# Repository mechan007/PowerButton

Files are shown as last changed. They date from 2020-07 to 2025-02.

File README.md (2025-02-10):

This is my first project on GitHub

This project was created out of the need to turn on and off a 3D printer with a button on the front panel. 
The emphasis was on powering the module directly from the mains voltage, also on the possible implementation
in existing devices, a button on the front panel and preventing shutdown by accidentally pressing the button.

The project is functional, but not finished (perhaps a prototype?),
it is intended for people who are familiar with this area.

Hopefully I will be able to continue and improve it.

I am also open to your questions, comments and suggestions,
but I warn you in advance that I am not able to respond immediately.

!!!Warning!!! This project uses high (mains) voltage! And can severely damage health, or cause death,
especially to people who do not know what they are doing! This project is not a final product,
it is not a recommendation or a guide! Everything you do with this, you do at your own risk!

Thank you for reading this far...

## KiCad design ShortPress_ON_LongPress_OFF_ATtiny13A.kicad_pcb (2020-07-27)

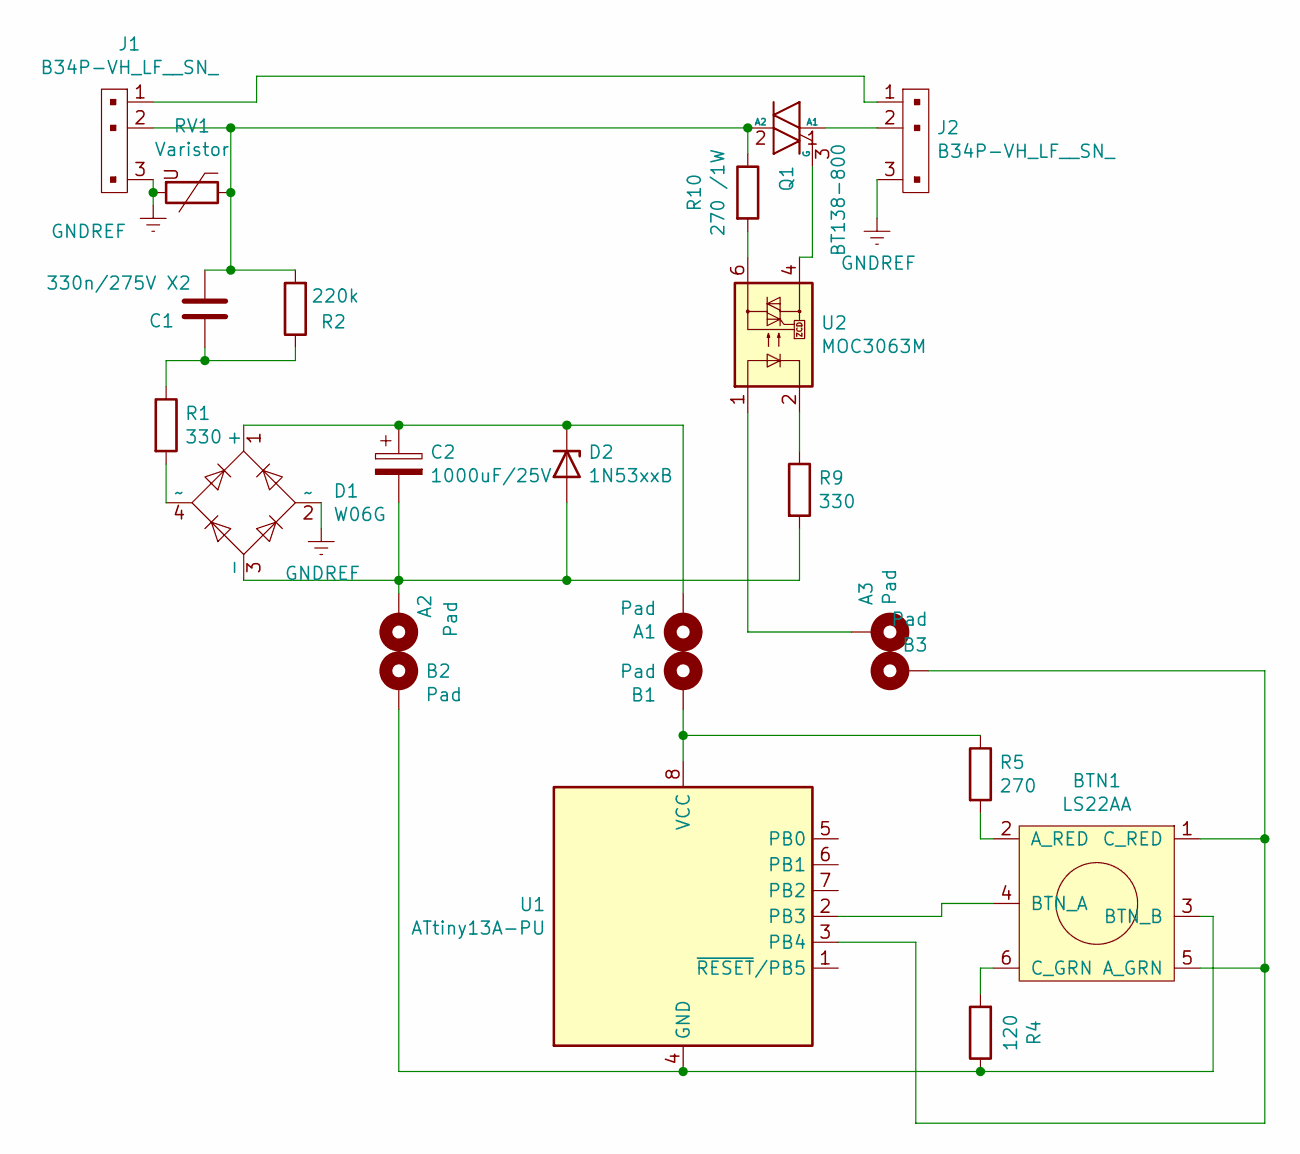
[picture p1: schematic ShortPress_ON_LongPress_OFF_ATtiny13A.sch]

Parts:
A1, A2, A3: Pad; PinHeader_1x01_P1.00mm_Vertical
B1, B2, B3: Pad; PinHeader_1x01_P1.00mm_Vertical
BTN1: LS22AA
C1: 330n/275V X2; C_Rect_L18.0mm_W8.0mm_P15.00mm_FKS3_FKP3
C2: 1000uF/25V; CP_Radial_D10.0mm_P5.00mm
D1: W06G; Diode_Bridge_Round_D9.8mm
D2: 1N53xxB; D_DO-201_P15.24mm_Horizontal
J1, J2: B34P-VH_LF__SN_; PinHeader_1x3_4_P3.96mm_Drill1.6mm
Q1: BT138-800; TO-220-3_Vertical
R1, R9: 330; R_Axial_DIN0207_L6.3mm_D2.5mm_P10.16mm_Horizontal
R2: 220k; R_Axial_DIN0207_L6.3mm_D2.5mm_P10.16mm_Horizontal
R4: 120; R_Axial_DIN0207_L6.3mm_D2.5mm_P10.16mm_Horizontal
R5: 270; R_Axial_DIN0207_L6.3mm_D2.5mm_P10.16mm_Horizontal
R10: 270 /1W; R_Axial_DIN0414_L11.9mm_D4.5mm_P15.24mm_Horizontal
RV1: Varistor; RV_Disc_D15.5mm_W4.8mm_P7.5mm
U1: ATtiny13A-PU; DIP-8_W7.62mm
U2: MOC3063M; DIP-6_W7.62mm

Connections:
GNDREF: D1.2 (~~), J1.3, J2.3, RV1.2
unnamed: A1.1, C2.1, D1.1 (+), D2.1 (K)
unnamed: A2.1, C2.2, D1.3 (-), D2.2 (A), R9.2
unnamed: A3.1, U2.1
unnamed: B1.1, R5.1, U1.8 (VCC)
unnamed: B2.1, BTN1.3 (BTN_B), R4.1, U1.4 (GND)
unnamed: B3.1, BTN1.1 (C_RED), BTN1.5 (A_GRN), U1.3 (PB4)
unnamed: BTN1.2 (A_RED), R5.2
unnamed: BTN1.4 (BTN_A), U1.2 (PB3)
unnamed: BTN1.6 (C_GRN), R4.2
unnamed: C1.1, R1.1, R2.1
unnamed: C1.2, J1.2, Q1.2 (A2), R2.2, R10.1, RV1.1
unnamed: D1.4 (~~), R1.2
unnamed: J1.1, J2.1
unnamed: J2.2, Q1.1 (A1)
unnamed: Q1.3 (G), U2.4
unnamed: R9.1, U2.2
unnamed: R10.2, U2.6

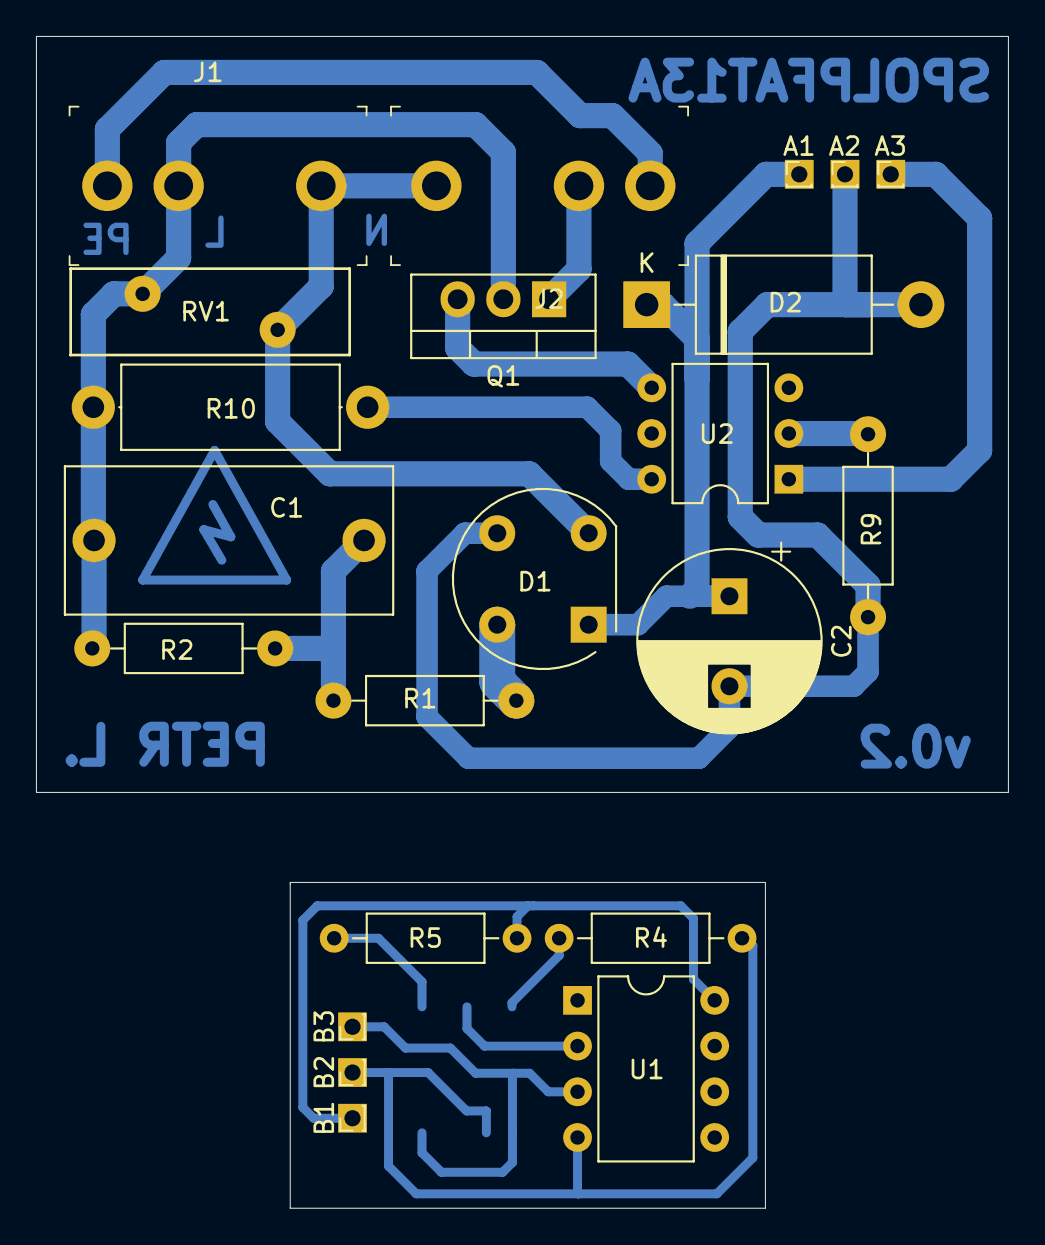
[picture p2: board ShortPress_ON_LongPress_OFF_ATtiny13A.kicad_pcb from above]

Board: 2 copper layers, 54.0 x 65.1 mm, 23 parts (1 on the bottom side), 18 nets.

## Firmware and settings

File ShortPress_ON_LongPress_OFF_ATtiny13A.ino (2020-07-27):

#include <Arduino.h>
/*
 * Project:         Powerbutton
 *
 * Created by:      Petr Lasak (mechan)
 *
 * Description:     Used for ATtiny13A (8-bit MCU).
 *                  After connecting to the mains, the device output is constantly low (OFF)
 *                  and does not respond for 1 second, the red LED lights up. After pressing
 *                  the button, the device switches to high (ON), the green LED lights up.
 *                  Switches back to low (OFF) if the button is held down for 3 seconds.
 *                  Then the device does not respond again for 5 seconds before it is possible
 *                  to press the button again and switch to high.
 *
 * Project folder
 * schema and PCB:  https://github.com/mechan007/Powerbutton
 *
 * Inspired by
 * and thanks:  https://arduinogetstarted.com/tutorials/arduino-button-long-press-short-press
 *
 */

// constants won't change. They're used here to set pin numbers:
const int button = 3; // the number of the pushbutton pin
const int LED = 4; // the number of the LED pin
const int SHORT_PRESS_TIME = 3000; // 3 seconds
const int LONG_PRESS_TIME  = 3000; // 3 seconds

// Variables will change:
int lastState = HIGH;  // the previous state from the input pin
int currentState;     // the current reading from the input pin
unsigned long pressedTime  = 0;
unsigned long releasedTime = 0;
bool isPressing = false;
bool isLongDetected = false;

void setup() {
  pinMode(LED, OUTPUT);
  pinMode(button, INPUT_PULLUP);
  delay(1000);
}

void loop() {
  // read the state of the switch/button:
  currentState = digitalRead(button);

  if(lastState == HIGH && currentState == LOW) {        // button is pressed
    pressedTime = millis();
    isPressing = true;
    isLongDetected = false;
  } else if(lastState == LOW && currentState == HIGH) { // button is released
    isPressing = false;
    releasedTime = millis();

    long pressDuration = releasedTime - pressedTime;

    if( pressDuration < SHORT_PRESS_TIME )
      digitalWrite(LED, HIGH); // A short press is detected
  }

  if(isPressing == true && isLongDetected == false) {
    long pressDuration = millis() - pressedTime;

    if( pressDuration > LONG_PRESS_TIME ) {
      digitalWrite(LED, LOW); // A long press is detected
      isLongDetected = true;
      delay(5000);
    }
  }

  // save the the last state
  lastState = currentState;
}
